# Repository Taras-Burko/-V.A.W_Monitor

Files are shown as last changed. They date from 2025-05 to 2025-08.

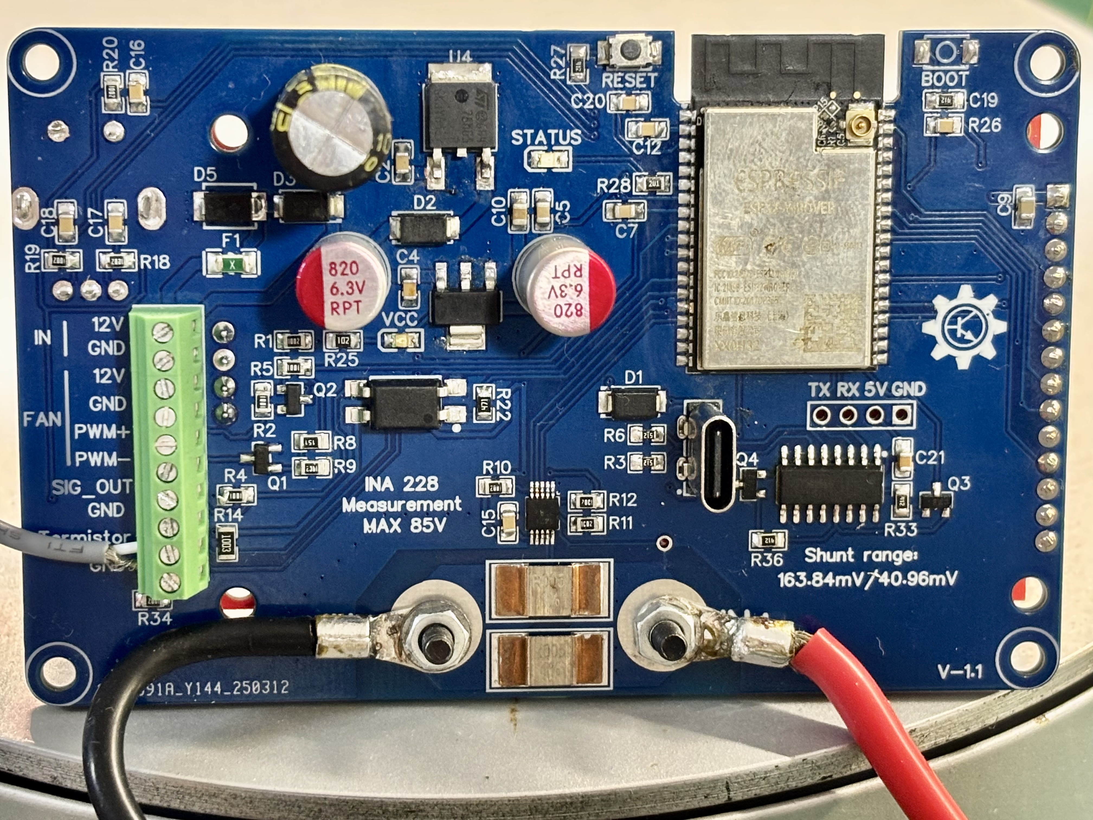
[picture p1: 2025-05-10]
IMG_2703.jpeg

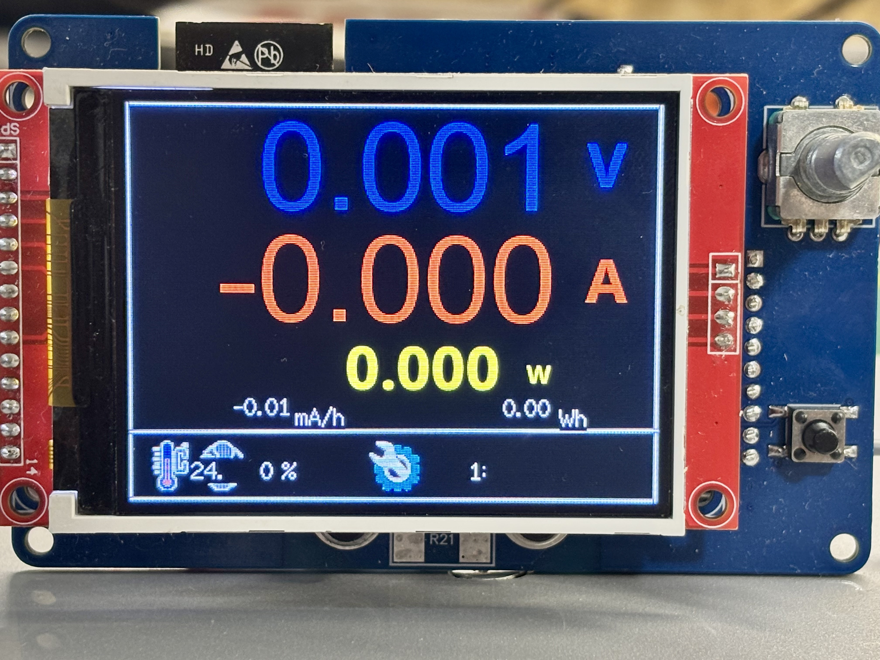
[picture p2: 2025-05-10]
IMG_2702.jpeg

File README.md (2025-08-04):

Увага.  Для коппіляції прошивки, потрібно змінити налаштування бібліотеки. 
1. Відкриваємо папку з усіма бібліотеками  "libraries "
2. Відкриваємо папку "TFT_eSPI" . якщо папки не існує потрібно встіновити бібліотеку TFT_eSPI.
3. Відкриваємо файл "User_Setup_Select.h"
4. Закоментовуємо  раядок   ""//#include <User_Setup.h> ""
5. Та  розкоментовуємо "#include <User_Setups/Setup42_ILI9341_ESP32.h>"
   Ящо у вас інший  тип контролера дисплея  , можна розкоментувати потрібний рядок.
   Готово можна пробувати  компілювати.  Не забудьте встановити решту  бібліотек.

# -V.A.W_Monitor
Високоточний монітор: Напруги,Струму,Потужності,Ємності,Енергії. Спроектований на ESP32 + INA228.  
Цей монітор  це вольт ампер метр високої точності , який можна застосувати для побудови   ЛБЖ, алектроного навантаження, та інший  корисних цілях. 
PCB розроблено для легкого збирання , мінімальний розмір  компонентів  0805 , всі компоненти можна знайти в відомих радіо магазинах . 





Характеристики  PCB 
1. Вхідна напруга  7-35В
2. Струм споживання  150 мА . 
3. Захист від перенапруги та невірної полярності.
4. USB-C розєм.
5. USB-UART конвентер.
6. Вбудований шунт
7. Використання  ESP32-WROWER + INA228
8. Вимірювання температури терморезистором
9. Контроль обертів кулера за допомогою PWM сигналу або за допомогою польового транзистора.
10. Вихід для  реле. 
11. Підтримка дисплею з сенсором +  енкодер  з кнопкою  + кнопка 
12. Монтаж диспею на плату.
13. Розмір плати 99х63 мм.

Реалізовані функції прошивки :

1.Вимірювання напруги  , струму , потужності , ємності  , та  енергії . 
2.Скидання  лічильника  ємності ,та енегії за допомогою кнопки .
3.Вимірювання температури ( транзистора  , радіатора ). 
4.Керування обертами вентилятора. 
5. Увімкнення та вимкнення режиму  керування електроного навантаження  , за допогою кнопки енкодера , та  налаштування  напруги  вимкнення за допомогою енкодера.

В планах також добавити  
1.	Додати кращу фільтрацію результатів. 
2.	Додати більше  налаштування переривань по досягненю необхідних значень .
3.	Реалізувати налаштавуння за допомогою сенсора дисплею.
4.	Додати  підтримку графіків. 
5.	Додати підтримку  блютуз в парі з  додатком.

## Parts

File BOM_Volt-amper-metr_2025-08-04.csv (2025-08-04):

ID | Name | Designator | Footprint | Quantity | Manufacturer Part | Manufacturer | Supplier | Supplier Part | Price
1 | 5mΩ | R16,R21,R7,R15 | R3920 | 4 | ASR-F-5-5F | yezhan(业展) | LCSC | C469440 | 0.508
2 | 2,8"_TFT_LCD_ILI9341_SPI COPY | LCD2 | TFT_LCD_SPI_ILI9341_2,8" | 1
3 | PEC11R-4015F-S0024 | SW1 | SW-TH_PEC11R-4XXXF-SXXXX | 1 | PEC11R-4015F-S0024 | BOURNS | LCSC | C143789 | 2.984
4 | TS-KG02S-AT43F | SW2 | SW-SMD_4P-L6.0-W6.0-P4.50-LS8.5 | 1 | TS-KG02S-AT43F | HANBO(汉博) | LCSC | C2874283 | 0.027
5 | DB125-2.54-10P-GN | U2 | CONN-TH_DB125-2.54-10P-GN | 1 | DB125-2.54-10P-GN-S | DORABO(地博电气) | LCSC | C918128 | 0.982
6 | GT-TC029B-H025-L1N | BOOT1,RES1 | SW-SMD_L3.9-W2.9-P4.15-LS5.0 | 2 | GT-TC029B-H025-L1N | G-Switch | LCSC | C843669 | 0.08
7 | 1200uF | C6,C8 | CAP-TH_BD8.0-P3.50-D0.6-FD | 2 | HS0J128M0811PC | HONOR(荣誉) | LCSC | C94439 | 0.173
8 | 100nF | C2,C4,C5,C12,C15,C21,C7 | C0805 | 7 | 0805B104K500NT | FH | LCSC | C38141 | 0.004
9 | 1500uF | C3 | CAP-TH_BD10.0-P5.00-D1.0-FD | 1 | SPT1CM152G12OR | Yunxing(云星) | LCSC | C556231 | 0.253
10 | 100nF | C16,C17,C18 | C0805 | 3 | CC0805KRX7R9BB103 | YAGEO | LCSC | C83170 | 0.005
11 | 104 | C19,C20 | C0805 | 2 | CC0805KRX7R9BB103 | YAGEO | LCSC | C83170 | 0.005
12 | SS34_C8678 | D1,D2,D3 | SMA_L4.3-W2.6-LS5.2-RD | 3 | SS34 | MDD(辰达半导体) | LCSC | C8678 | 0.028
13 | SMBJ28A-AT | D5 | SMB_L4.6-W3.6-LS5.3-R-RD | 1 | SMBJ28A-AT | Brightking Elec (TAIWAN) | LCSC | C523310 | 0.091
14 | CFS12V3T5R0 | F1 | F1206 | 1 | CFS12V3T5R0 | TA-I Tech | LCSC | C163128 | 0.036
15 | 0805G (Green) | LED1 | LED0805-RD_GREEN | 1 | 0805G (Green) | KENTO | LCSC | C2297 | 0.011
16 | whiteLEDSMD | LED2 | LED0805-FD | 1 | whiteLEDSMD | KENTO | LCSC | C34499 | 0.018
17 | AO3400A | Q1 | SOT-23-3_L2.9-W1.6-P1.90-LS2.8-BR | 1 | AO3400A | AOS | LCSC | C20917 | 0.077
18 | BC847 | Q2,Q3,Q4 | SOT-23-3_L2.9-W1.3-P1.90-LS2.4-BR | 3 | BC847 | CJ（江苏长电/长晶） | LCSC | C2910145 | 0.018
19 | 10kΩ | R1,R9 | R0805 | 2 | RS-05K103JT | FH(风华) | LCSC | C115295 | 0.002
20 | 1kΩ | R2,R4,R5 | R0805 | 3 | RS-05K102JT | FH | LCSC | C115302 | 0.002
21 | 5.1kΩ | R3,R6 | R0805 | 2 | RS-05K5101FT | FH(风华) | LCSC | C118848 | 0.002
22 | 300Ω | R8 | R0805 | 1 | 0805W8J0301T5E | UNI-ROYAL(厚声) | LCSC | C25304 | 0.002
23 | 10kΩ | R10,R11,R12,R18,R19,R20,R33,R36 | R0805 | 8 | RS-05K103JT | FH | LCSC | C115295 | 0.002
24 | 100kΩ | R14 | R0805 | 1 | ERJ6RBD1003V | PANASONIC | LCSC | C336855 | 0.027
25 | 300Ω | R22 | R0805 | 1 | 0805W8J0301T5E | UniOhm | LCSC | C25304 | 0.002
26 | 200 | R25,R28 | R0805 | 2 | RC0805JR-07200RL | YAGEO | LCSC | C114746 | 0.002
27 | 10K | R26,R27,R34 | R0805 | 3 | 0805W8F3571T5E | UniOhm | LCSC | C17613 | 0.002
28 | AMS1117-3.3_C347222 | U1 | SOT-223-4_L6.5-W3.5-P2.30-LS7.0-BR | 1 | AMS1117-3.3 | UMW(友台半导体) | LCSC | C347222 | 0.04
29 | 78M05D | U4 | TO-252-2_L6.6-W6.1-P4.57-LS9.9-BR-CW | 1 | 78M05D | 晶导微电子 | LCSC | C7528188 | 0.128
30 | INA228AIDGST | U6 | VSSOP-10_L3.0-W3.0-P0.50-LS4.9-BL | 1 | INA228AIDGST | TI(德州仪器) | LCSC | C2862904 | 7.386
31 | ESP32-WROVER | U8 | WIFI-SMD_ESP32-WROVER-E | 1 | ESP32-WROVER-IE(8MB) | Espressif Systems | LCSC | C701351 | 4.528
32 | PC817X2NIP0F | U9 | SMD-4_L4.6-W6.5-P2.54-LS10.2-TL | 1 | PC817X2NIP0F | SHARP | LCSC | C7437
33 | MTP125 | U14 | HDR-TH_4P-P2.54-V | 1 | MTP125-1104S1 | MINTRON | LCSC | C358686 | 0.022
34 | CH340C | U15 | SOP-16_L10.0-W3.9-P1.27-LS6.0-BL | 1 | CH340C | WCH(南京沁恒) | LCSC | C84681 | 0.533
35 | MC-802YC-H105 | USB1 | USB-TH_MC-802YC-H105 | 1 | MC-802YC-H105 | HANBO(汉博) | LCSC | C3039301 | 0.275
36 | 22uF | C9,C10 | C0805 | 2 | CL21A226MAYNNNE | SAMSUNG(三星) | LCSC | C602037 | 0.023

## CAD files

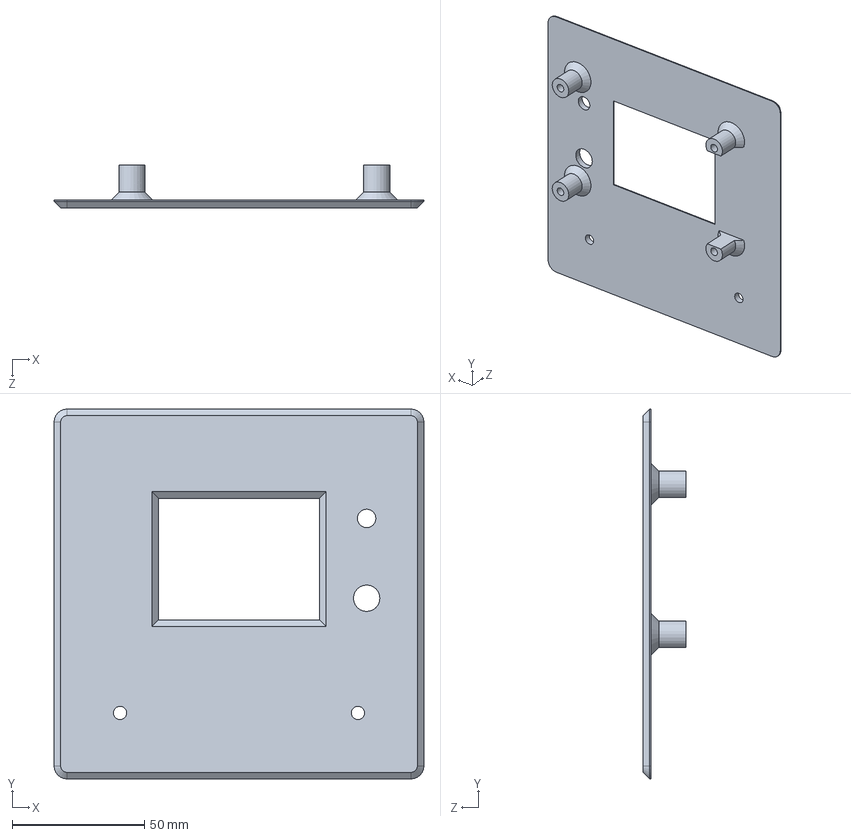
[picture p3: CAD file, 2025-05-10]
Panel_3D_Model/VAM Panel.SLDPRT
140.0 x 140.0 x 16.3 mm

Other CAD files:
Panel_3D_Model/VAM Panel.STL

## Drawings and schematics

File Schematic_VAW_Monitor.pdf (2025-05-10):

# FAN control

# ESP32

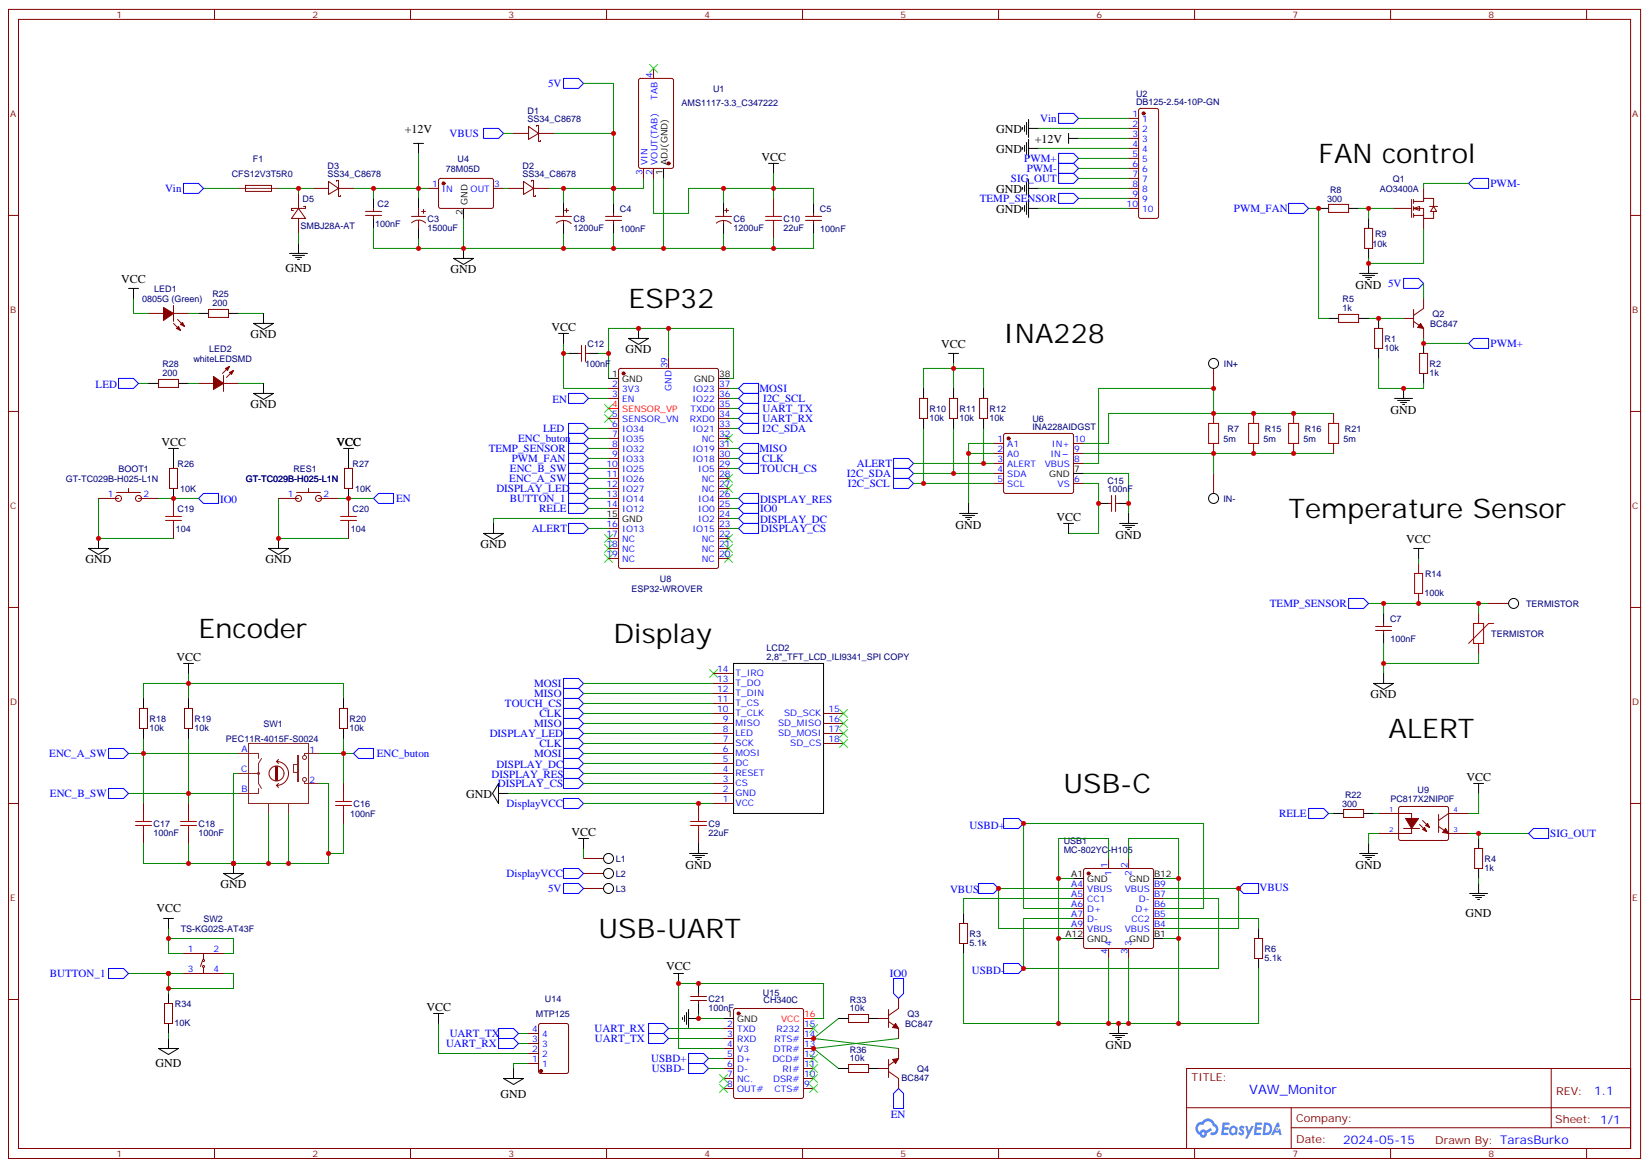
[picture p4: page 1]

DSR# 10 RI# 11 DCD# 12 DTR# 13 RTS# 14 R232 15 VCC 16

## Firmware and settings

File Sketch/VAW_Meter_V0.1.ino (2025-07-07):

#include <Arduino.h>
#include "esp32-hal-ledc.h" // бібліотека esp32 для PWM
#include "INA228.h"
INA228 INA(0x40); // Адреса INA228
#include <TFT_eSPI.h> // Hardware-specific library
#include <SPI.h>
#include "PNG_file.h" // файл з зображеннями  PNG для візуалізації
TFT_eSPI tft = TFT_eSPI();       // Invoke custom library
#include "AiEsp32RotaryEncoder.h"
#include <EEPROM.h>

#include "NotoSansBold15.h"     //Файл з плавними шрифтами
#include "NotoSansBold36.h"     //Файл з плавними шрифтами
#include "Unicode_Test_72.h"    //Файл з плавними шрифтами


// Stock font and GFXFF reference handle
#define GFXFF 1
#define FF18 &FreeSans12pt7b

// Custom are fonts added to library "TFT_eSPI\Fonts\Custom" folder
// a #include must also be added to the "User_Custom_Fonts.h" file
// in the "TFT_eSPI\User_Setups" folder. See example entries.
#define CF_OL24 &Orbitron_Light_24
#define CF_OL32 &Orbitron_Light_32
#define CF_RT24 &Roboto_Thin_24
#define CF_S24  &Satisfy_24
#define CF_Y32  &Yellowtail_32

//                        Налаштування  роботи  Охолодження 
//====================================================================================
 int Temp_min = 29 ; // Минимальная температура при которой начнет работать ШИМ вентилятора.
 int Temp_max = 60 ; // Температура при которой скорость вентилятора будет максимальной.
 int pwm_min =20;    // мінімальне значення шим при якому  починає обертитись вентилятор. 
 int pwm_max =255;   // максимальне значення для вентилятора. 
 int PWM_freq=5000;    // Частота PWM. при високих частотах вентилятор може некореткно працювати. Частоту потрібно підбирати індивідуально.

//                          Налаштування  Терморезистора  
//====================================================================================
 #define B 3950 // B-коєфіцієнт терморезистора 
 #define SERIAL_R 100 // Опір резистора R14 на платі, 100 кОм
 #define THERMISTOR_R 100// Номінальний опір терморезистора , 100 кОм
 #define NOMINAL_T 25 // номінальна  температура (при якій  терморезистор = 100 кОм)
  


#define ROTARY_ENCODER_A_PIN 25
#define ROTARY_ENCODER_B_PIN 26
#define ROTARY_ENCODER_BUTTON_PIN 35
#define ROTARY_ENCODER_VCC_PIN -1 /* 27 put -1 of Rotary encoder Vcc is connected directly to 3,3V; else you can use declared output pin for powering rotary encoder */

#define ROTARY_ENCODER_STEPS 4
AiEsp32RotaryEncoder rotaryEncoder = AiEsp32RotaryEncoder(ROTARY_ENCODER_A_PIN, ROTARY_ENCODER_B_PIN, ROTARY_ENCODER_BUTTON_PIN, -1, ROTARY_ENCODER_STEPS);
void IRAM_ATTR readEncoderISR(){rotaryEncoder.readEncoder_ISR(); }

 
  float cicle;
  int x,y;
  char PWM0;
  int PWM,PWM_power,display_backlight,rty;
  uint32_t ms_display,ms_led,ms_PWM,ms_SP,Time;
  bool flag_led,Accumulation_flag,flag_enc_but,flag_enc;
  float Voltage,Current,Power,Temperature,Charge,Energy,Voltege_fil,Curent_fil,Set_voltege,Encoder_memory;
  char Voltage_display[10]; 
  char Current_display[10]; 
  char Power_display[8]; 
  char Temperature_display[8]; 
  char Charge_display[12];
  char Energy_display[12];
  char PWM_display[6];
  char Set_voltege_display[10];
  char cicle_display[10];
 


// #define Enc_A_pin       25    // Енкодер фаза А
 //#define Enc_B_pin       26    // Енкодер фаза В
// #define Enc_but_pin     35    // Кнопка енкодера
 #define button_pin      14    // Кнопка 
 #define led_pin         34     // індикація світлодіода
 #define temp_pin        32    // пін для терморезистора.
 #define PWM_pin         33    // порт для керування PWM вентилятора
 #define relay_pin       12    // реле

//====================================================================================
//                                    Setup
//====================================================================================
void setup() {
Serial.begin(115200);

delay(100); 

 Wire.begin(); 
  if (!INA.begin() ) // Ініціалізація INA228
  {
    Serial.println("INA228 not connect."); // Якщо ініціалізація відсутня виводити помилку
    while(1);
  }

//                        Налаштування  роботи  INA228
//====================================================================================

 INA.setMode(0x0F); // Режим роботи, безперевне вимірювання напруги , шунта ,тепмератури = 0x0F
 INA.setBusVoltageConversionTime(5);   // Час перетворення  АЦП вольтметра us  50=0,84=1,150=2,280=3,540=4,1052=5,2074=6,4120=7 us 
 INA.setShuntVoltageConversionTime(5); // Час перетворення  АЦП Амперметра  50,84,150,280,540,1052,2074,4120 us
 INA.setTemperatureConversionTime(5);   // Час перетворення  АЦП температури 50,84,150,280,540,1052,2074,4120 us
 INA.setAverage(5); // Кількість вибірок 1=0,4=1,16=2,64=3,128=4,254=5,512=6,1024=7 
 INA.setMaxCurrentShunt(12, 0.0024923); // Задати  значчення шунта ( ток , опір шунта);
 //INA.setADCRange(0);  // flag = 0 => 164 мВ, 1 => 41 мВ
 INA.setTemperatureCompensation(1); //Увімкнути температурну компенсацію шунта. 0 - Вимкнути , 1-Увімкнути .
 INA.setShuntTemperatureCoefficent(50); // Коєфіцієнт температурної компенсації щунта, визначається в  ppm/°C. Його можна знайти в мануалі на шунт.  Переважно це значення від 50 ppm/°C до 200 ppm/°C взалежності від типу шунта який використовується. 
 
//====================================================================================


 tft.init();                   // ініціалізація дисплею . 
 digitalWrite(TFT_BL, LOW);
 tft.setRotation(3);           // Орієнтація  дисплею.
 tft.fillScreen(TFT_BLACK);    // Залити дисплей .

 pinMode(led_pin , OUTPUT);    // LED індикації статусу роботи 
 pinMode(relay_pin , OUTPUT);  // Дискретний сигнал на вихід. 
 //pinMode(Enc_but_pin, INPUT );  // Вхід кнопки.
 pinMode(temp_pin, INPUT );    // Вхід АЦП терморезистора.
 attachInterrupt(button_pin, Reset_Accumulation, FALLING);  // Переривання для скидання лічильника є мності та енергії.Кнопка енкодера.
 ledcAttach(PWM_pin, PWM_freq, 8);                           // Налаштовуємо PWM (канал , частота , розширеня 1-16)
 ledcAttach(TFT_BL, 5000, 8);  
 //ledcAttachChannel(led_pin, 0); //// Налаштовуємо PWM (порт PWM виходу , канал)
 Accumulation_flag =  0;
analogReadResolution(11); // Розщирення АЦП ESP32
 
 rotaryEncoder.begin();
 rotaryEncoder.setup(readEncoderISR);
 rotaryEncoder.setBoundaries(-2000, 1000, false); //minValue, maxValue, circleValues true|false (when max go to min and vice versa)
 rotaryEncoder.setAcceleration(150);

 Display_ramka();
 EEPROM.begin(512);
 //Set_voltege = EEPROM.read(0);  // Чтение данных
 EEPROM.get(0, Encoder_memory);// - читает данные по адресу и сам записывает их в данные - указанную переменную
 Set_voltege = Encoder_memory ;
 flag_enc_but =1;
 display_backlight=1;
}
//====================================================================================
//                                    Loop
//====================================================================================
void loop() {
 if( display_backlight < 255 ){
  rty++;
 display_backlight= pow(rty,3)/50;
  if( display_backlight > 255 ){display_backlight=255;}
  ledcWrite(TFT_BL, display_backlight);
 }
  
  if ( Accumulation_flag ==1  ){  // Якщо кнопка нажата  скидати  лічильник.
   INA.setAccumulation(1);
   Serial.println("setAccumulation");
   Accumulation_flag =0; 
  }
  Voltage=INA.getBusVoltage();
  Current=INA.getCurrent();
  Power=INA.getPower();
  Charge=INA.getCharge();
  Charge/=3.6 ;     // Конвертуємо кулони в mA/h
  Energy=INA.getWattHour();
  //Energy=INA.getMicroJoule();

  //if(Voltege < 0.00099) {Voltege=0;}
  //if(Curent < 0.00099) {Curent=0;}

  //Voltege_fil += (Voltege - Voltege_fil) * 0.05; // Фільтрація напруги 
  //Voltege = Voltege_fil ;
  //Curent_fil += (Curent - Curent_fil) * 0.05;    // Фільтрація току 
  //Curent = Curent_fil ;
  

 dtostrf( Voltage    , 6, 3, Voltage_display);
 dtostrf( Current    , 6, 3, Current_display);
 dtostrf( Power      , 7, 3, Power_display);
 dtostrf( Temperature, 4, 1, Temperature_display);
 dtostrf(  Charge    , 8, 2, Charge_display);
 dtostrf(  Energy    , 8, 2, Energy_display);
 dtostrf( PWM_power  , 5, 0, PWM_display);
 dtostrf( Set_voltege, 6, 2, Set_voltege_display);
 dtostrf( cicle      , 5, 1, cicle_display);
  S_P();          // Вивід даних в СОМ порт.
  Display();      // Візуалізація на  дисплей 
  //Led_blink();    // LED Статус роботи
  speed_fan (); //  Керування охолодженям.
  rotary_loop();
  led_cicle();
  if ( Voltage<=Set_voltege && flag_enc_but==1){
   digitalWrite(relay_pin, HIGH);
  }
   else{digitalWrite(relay_pin, LOW);
   }

   if (flag_enc==1 ){
     EEPROM.put(0, Set_voltege);  // Запись данных
     EEPROM.commit();   // Сохранение изменений
     //EEPROM.end();  // Освобождение ресурсов
     flag_enc=0;
    }

}

void Reset_Accumulation () {
  Accumulation_flag =1;
}

void Led_blink () {
  if (( millis()- ms_led ) >= 200) {
   flag_led = !flag_led;
   digitalWrite(led_pin, flag_led);
   ms_led=millis();
  } 
}

void speed_fan (){

if (( millis()- ms_PWM ) >= 1000) {
 uint32_t t = analogReadMilliVolts( temp_pin ); // Зчитуємо  значення AЦП на порту ESP32.
 Temperature = t * SERIAL_R /(3300 - t )  ; // Опір терморезистора 
 //Serial.println   ( Temperature );
 Temperature = log(Temperature / THERMISTOR_R); // ln(R/Ro)
 Temperature /= B; // 1/B * ln(R/Ro)
 Temperature += 1.0 / (NOMINAL_T + 273.15); // + (1/To)
 Temperature = 1.0 / Temperature; // Invert
 Temperature -= 273.15;
     //Розраховуємо начення ШИМ вентилятора  в залежності від температури терморезистора. 
  if (Temperature >= Temp_min && Temperature <= Temp_max )  {
   PWM =  ((Temperature - Temp_min ) * (pwm_max - pwm_min) / ( Temp_max - Temp_min )) + pwm_min ; }
   else if (Temperature < Temp_min)  { PWM = 0;}
   else if (Temperature >= Temp_max)  {PWM = 255;}
   ms_PWM=millis();
   ledcWrite(PWM_pin, PWM); // (канал , значення PWM)
   if (PWM>0){
     PWM_power  = 100*(PWM-pwm_min)/(pwm_max-pwm_min); // Розрахунок  потущності ШИМ для візуалізації.
    }
  }
}
void led_cicle(){
 cicle=1000/((millis()-Time));
 Time = millis();
 //char cicle_display[6];
}

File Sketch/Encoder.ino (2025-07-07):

void rotary_onButtonClick()
{
	static unsigned long lastTimePressed = 0;
	//ignore multiple press in that time milliseconds
	if (millis() - lastTimePressed < 100)
	{
		return;
	}
	lastTimePressed = millis();
	Serial.print("button pressed ");
	Serial.print(millis());
	Serial.println(" milliseconds after restart");
}

void rotary_loop()
{
	//dont print anything unless value changed
	if (rotaryEncoder.encoderChanged() )
	{
		//Serial.print("Value: ");
		//Serial.println(rotaryEncoder.readEncoder());

		Set_voltege=rotaryEncoder.readEncoder();
		Set_voltege/=100;
		Set_voltege+=Encoder_memory;
		if(Set_voltege<0 ){
			Set_voltege=0;
		}
		flag_enc=1;
		
	}
	if (rotaryEncoder.isEncoderButtonClicked())
	{
		rotary_onButtonClick();
    flag_enc_but=!flag_enc_but;
	}
}
